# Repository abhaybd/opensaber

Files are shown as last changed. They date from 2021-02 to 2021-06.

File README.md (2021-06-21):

# OpenSaber

An LED lightsaber, designed and built from scratch. This project took a while to complete, mostly due to classes and tests, but it's finally done!

<p align="center">
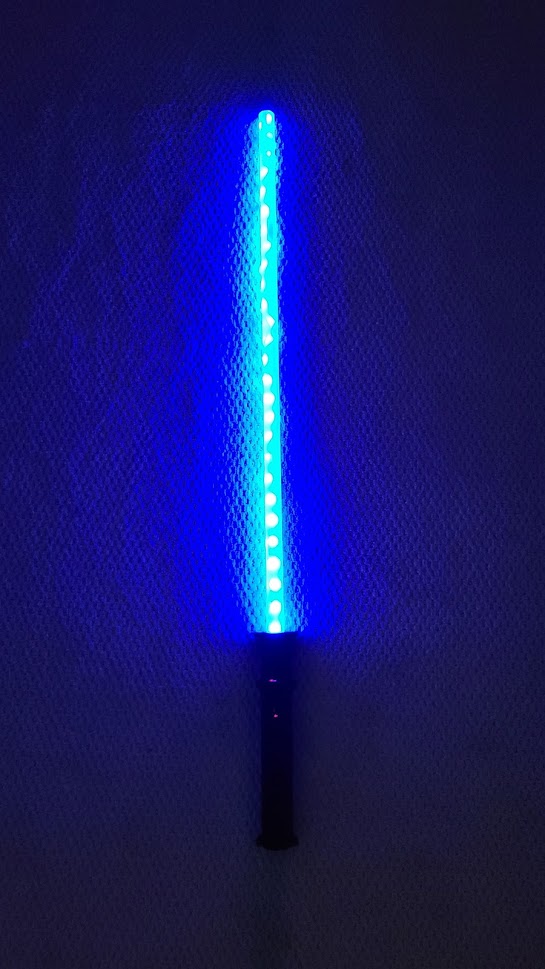
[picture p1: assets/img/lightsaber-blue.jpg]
    
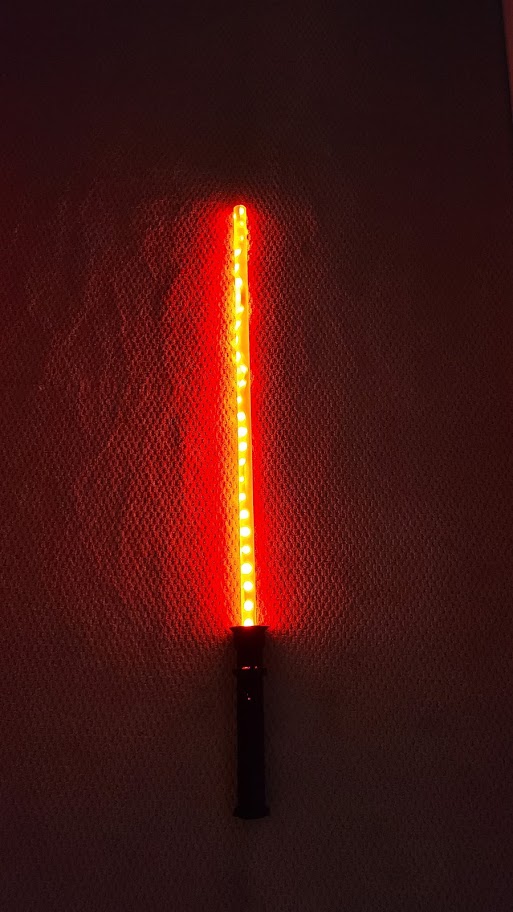
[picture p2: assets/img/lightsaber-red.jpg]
    
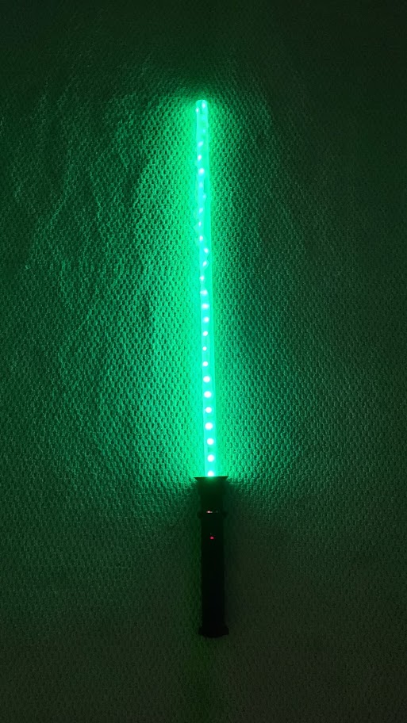
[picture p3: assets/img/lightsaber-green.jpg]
    
</p>

My goal with this document isn't to analyze every step of the process in building this project, but merely to point out the parts that I found particularly interesting, challenging or fun. Therefore, this probably isn't a proper "postmortem", but rather a "highlights reel", maybe.

## High-Level Overview

I designed hilt of the lightsaber using Fusion360, and then 3d-printed it. The hilt is made of 5 pieces, and held together by screws. The blade is a frosted acrylic tube, with a strip of LEDs inside.

### Electronics

Inside the hilt, there is a microcontroller (Trinket M0), a gyroscope (MPU6050), a speaker, an audio amplifier, a power converter (5V boost), and a Li-Ion battery. The single microcontroller runs the lights, sounds, user input, and reads sensor information from the gyro. Using the rotational velocity information, the brightness of the blade and the volume of the lightsaber is dynamically adjusted according to how fast the lightsaber is swinging, which makes the blade feel more "alive". The LED strip in the blade is individually-addressable, allowing the  blade to be any color, as well as having ignition and extinguishing animations.

### Physical

Since my 3D printer has a size limitation of <6 inches in each dimension, the hilt needed to be printed in several pieces. There are 2 back pieces, 2 front pieces, and then an emitter piece, which is where the blade is mounted. The electronics are mounted into the back pieces, and the user controls are mounted on the front pieces.

I'm not particularly skilled with CAD, so the first draft of the hilt was pretty bad. I highly overestimated the space I had inside the hilt, so I designed hilt to be mostly solid plastic, with mounting points for the electronics. 

<p align="center">
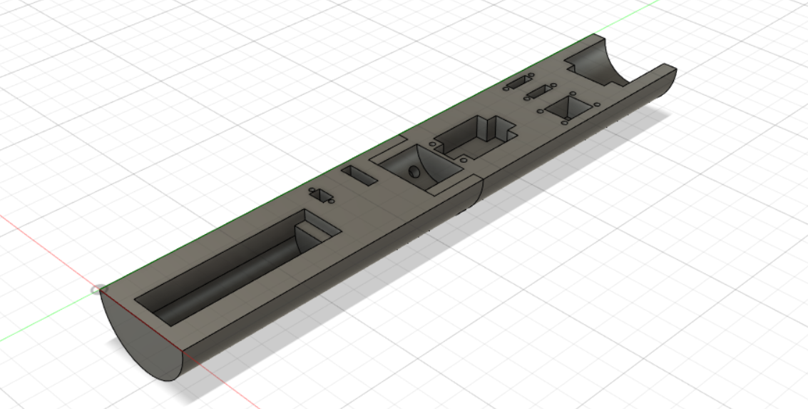
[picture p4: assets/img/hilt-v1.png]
Hilt-V1
    
</p>

As you can see, in the second iteration I tried to mount electronics on the inner walls, resulting in much more space.

<p align="center">
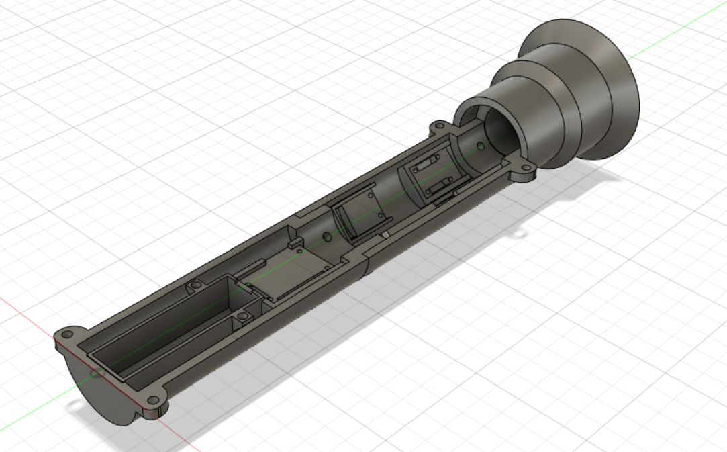
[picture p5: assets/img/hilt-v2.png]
Hilt-v2
    
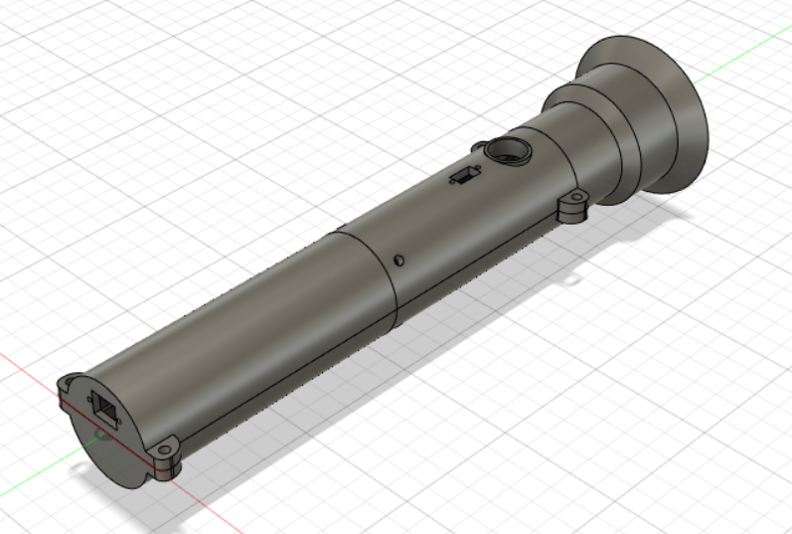
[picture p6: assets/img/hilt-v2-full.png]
    
</p>

You'll notice that on the bottom of the hilt there's a hole. This was intended for a charging cable, so the lightsaber could be charged by just plugging it in. However, with the amount of wires filling up the inside of the hilt, there was no room for such a thick cable, so that had to be scrapped. As a result, unfortunately, in order to charge the battery, the hilt must be disassembled.

## Roadblock - LED Write Latency

A major problem I ran into early in the project was the issue of having the singular microcontroller driving everything at the same time. For example, while the lightsaber is on, the microcontroller must monitor the gyro, send audio signals, adjust the LEDs, and handle user input. 

The microcontroller sends audio signals using an analog output, which allows it to dynamically change the volume according to the speed of the saber. A downside of this, however, is that audio data cannot be buffered, which would allow for much more flexible timing. Therefore, the audio must be played real-time, which means that the timing should be very consistent. While the lightsaber is on, the sound is played back at a frequency of 6kHz, which means that the loop period should be, at maximum, 0.000167 seconds, or 167 microseconds. Normally, this should be fine, and would be well within the abilities of the microcontroller. However, updating the LED strip complicates things, for a few reasons.

First, updating the LEDs is fairly expensive, and would cause the loop time to exceed the maximum allowable period. Second, the library being used for the LEDs, the Adafruit NeoPixel library, suspends interrupts while running. Since all mechanisms to measure time depend on interrupts, the system would have no way of knowing how much time was spent commanding the LEDs, and would therefore mess up all scheduling logic.

The best solution I found through research was to change the LED update mechanism to DMA. DMA, or Direct Memory Access, would essentially repurpose the communication hardware on the microcontroller (such as I2C, SPI, etc.) to instead send signals to the LEDs. Since this communication is handled by the hardware, this would happen completely independently of the CPU, so updating the LEDs would become absolutely free, in terms of CPU time.

However, an issue was that the communication hardware was already in use, since the gyro uses I2C (a communication protocol) to send data to the microcontroller. The microcontroller can't do both DMA and I2C at the same time, which is obviously a problem.

My solution to this problem was to bit-bang the I2C communication with the gyro. "Bit-banging" is when you use software to do things that would normally be done by hardware. That is, the protocol would be handled by individually flipping pins low and high in software. Since the existing gyro library uses the hardware I2C, I had to rewrite the gyro library from scratch to use the bit-banged I2C implementation. There were a lot of little bugs that came up here, since I was trying to get meaningful information by writing low-level communication from scratch. After a while (and frying a gyro) I was able to iron out all the issues with my gyro library, and it's working pretty reliably.

Obviously, since the I2C is now being run in software, we lose some of the advantage we gained from switching the LEDs to DMA. However, it's still a significant net-positive, since the bit-banged I2C is still reasonably fast.

The new code can comfortably run everything at the required 6kHz update speed, so everything works like a charm. In fact, during the ignition and extinguish animations, since there is no gyro needed, the cycle is run at 12kHz instead of 6, resulting in a little better sound quality.

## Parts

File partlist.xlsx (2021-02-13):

Name | Type | Notes | Link | Qty | Price | Total for Part | Dims (mm)
Trinket M0 | Microcontroller |  | https://www.adafruit.com/product/3500 | 1 | $8.95 | $8.95 | 27 x 15.3 x 2.75 | Subtotal: | $86.45
NeoPixel LED Strip | LED Strip | 1m each, 30LED/m | https://www.adafruit.com/product/4801 | 2 | $12.50 | $25.00 |  | Est. Total: | $106.10
Li-Ion Battery | Battery pack | 3.7V @ 2.2Ah | https://www.adafruit.com/product/1781 | 1 | $9.95 | $9.95 | 69 x 18 x 18
PowerBoost 500 | Boost Converter | Also charges battery | https://www.adafruit.com/product/1944 | 1 | $14.95 | $14.95 | 22 x 37 x 2
6-DoF Accel+Gyro | Accel+Gyro | I2C | https://www.adafruit.com/product/3886 | 1 | $6.95 | $6.95 | 26 x 17.8 x 4.6
FtM Micro USB | Cable | For power to boost | https://www.adafruit.com/product/3258 | 1 | $4.95 | $4.95
Wire spool - 25ft | Wires | Solid core, 22awg | https://www.adafruit.com/product/288 | 1 | $2.95 | $2.95
3-wire block | Wire connector | pack of 3 | https://www.adafruit.com/product/866 | 1 | $4.95 | $4.95 | 8.3 x 18.6 x 29.9
Pushbutton | Button | Normal open | https://www.adafruit.com/product/1505 | 1 | $0.95 | $0.95 | 15 x 15.5
JST socket to cable | Wires | 200mm | https://www.adafruit.com/product/4046 | 1 | $0.95 | $0.95
Audio Amp | Audio | 2.5W | https://www.adafruit.com/product/2130 | 1 | $3.95 | $3.95
Mini speaker | Speaker | 8ohm 1W | https://www.adafruit.com/product/3923 | 1 | $1.95 | $1.95

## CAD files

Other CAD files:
assets/cad/Hilt.f3d

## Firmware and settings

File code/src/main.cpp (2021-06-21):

#include <Arduino.h>
#include <Adafruit_NeoPixel_ZeroDMA.h>

#include <cmath>

#include "MPU6050_Gyro.h"

#undef roundf

// import animation sounds
#include "IgnitionSound.h"
#include "HumSound.h"
#include "Extinguish.h"

//#define DEBUG
//#define GYRO_OPTIONAL

// dma requires pin 4
constexpr int LED_PIN = 4;

// 60 LEDS, where the middle of the strip is the tip of the blade, and the ends of the strip is the base
constexpr int NUM_LEDS = 59;
constexpr int LED_IDX_START = 0;
constexpr int LED_IDX_MIDDLE = 29;
constexpr int LED_IDX_END = 58;

constexpr int AUDIO_PIN = A0;

constexpr int BUTTON_PIN = 3;

constexpr int DAC_PRECISION = 10;

constexpr uint64_t US_PER_SEC = 1000000ull;

MPU6050_Gyro gyro(false, 0, 2);
Adafruit_NeoPixel_ZeroDMA leds(NUM_LEDS, LED_PIN, NEO_GRB + NEO_KHZ800);

constexpr uint8_t baselineBrightness = 128; // unitless, out of 255
constexpr uint8_t maxBrightness = 255; // unitless, out of 255
constexpr ulong gyroUpdatePeriod = 50000; // microseconds
constexpr float maxRotVel = 200; // degrees per second
float humMaxScaleFactor; // initialized in setup()
constexpr uint CHANGE_COLOR_PRESS_DURATION = 1000; // ms
constexpr uint EXTINGUISH_PRESS_DURATION = 50; // ms
const int colors[] = {0xFF0000, 0x00FF00, 0x0000FF, 0xFFFF00};

// state variables
uint8_t colorIndex = 0;
int color = colors[colorIndex];
bool gyroInitialized = false;
bool shouldExtinguish = false;
ulong buttonPressedTime = millis();

template<typename T>
float maxScaleFactor(uint size, const T sound[], float maxVal) {
    if (size == 0) return 1;
    T max = sound[0];
    for (uint i = 1; i < size; i++) {
        if (max < sound[i]) max = sound[i];
    }
    return max == 0 ? 1 : maxVal / static_cast<float>(max);
}

template<typename T>
T clamp(T val, T low, T high) {
    return val < low ? low : (val > high ? high : val);
}

template<typename T, int size>
constexpr uint arrLen(T(&)[size]) {
    return size;
}

void writeAudio(uint value, int precision) {
    // shift either left or right as necessary
    if (precision > DAC_PRECISION) {
        value >>= precision - DAC_PRECISION;
    } else if (precision < DAC_PRECISION) {
        value <<= DAC_PRECISION - precision;
    }
    // this method internally masks the 10 LSB, so we don't have to
    analogWrite(AUDIO_PIN, value);
}

[[noreturn]] void end(bool flashError = true) {
    leds.clear();
    writeAudio(0, DAC_PRECISION);
    while (true) {
        if (flashError) {
            int errorColor = 0x800000;
            leds.fill(errorColor);
            leds.show();
            delay(1000);

            leds.clear();
            leds.show();
            delay(1000);
        }
    }
}

float getRotVel() {
    RotVel rotVel{};
    gyro.get(rotVel);
    // magnitude of axis-angle representation
    return hypotf(rotVel.x, rotVel.z); // we don't care about y rotation, since that's just roll
}

// extinguish and turn off the blade
void extinguish() {
    // disable interrupt while extinguishing
    detachInterrupt(digitalPinToInterrupt(BUTTON_PIN));

    // extinguish leds from top to bottom
    constexpr uint64_t soundLen = arrLen(extinguishSound.sound);
    uint soundTimeMicros = soundLen * US_PER_SEC / extinguishSound.freq;
    int soundIdx = -1; // the last sound sample that has been played
    // these represent the largest and smallest indexes that have not yet been turned off
    int oldLed1Idx = LED_IDX_MIDDLE; // counts down
    int oldLed2Idx = LED_IDX_MIDDLE; // counts down
    ulong time = micros();
    ulong start = time;
    constexpr int OFF_COLOR = 0;
    constexpr uint extinguishTime = extinguishEnd - extinguishStart;

    while (time - start < soundTimeMicros) {
        uint elapsedTime = time - start;
        // the intermediate cast to ull is to prevent overflow from multiplication
        int newSoundIdx = static_cast<int>(static_cast<uint64_t>(elapsedTime) * extinguishSound.freq / US_PER_SEC);
        if (newSoundIdx > soundIdx) {
            soundIdx = newSoundIdx;
            writeAudio(extinguishSound.sound[soundIdx], extinguishSound.precision);

            if (elapsedTime >= extinguishStart) {
                // write to leds
                uint elapsedTimeLed = clamp(elapsedTime - extinguishStart, 0u, extinguishTime);
                // interpolate the elapsed time between the middle and both the start and end
                int led1Idx = static_cast<int>(
                        LED_IDX_MIDDLE - ((elapsedTimeLed * (LED_IDX_MIDDLE - LED_IDX_START)) / extinguishTime));
                int led2Idx = static_cast<int>(
                        LED_IDX_MIDDLE + ((elapsedTimeLed * (LED_IDX_END - LED_IDX_MIDDLE)) / extinguishTime));

                bool shouldShow = false;
                // led 1 counts down from MIDDLE
                while (oldLed1Idx >= led1Idx) {
                    leds.setPixelColor(oldLed1Idx--, OFF_COLOR);
                    shouldShow = true;
                }
                // led 2 counts up from MIDDLE
                while (oldLed2Idx <= led2Idx) {
                    leds.setPixelColor(oldLed2Idx++, OFF_COLOR);
                    shouldShow = true;
                }
                if (shouldShow) {
                    leds.show();
                }
            }
        }
        time = micros();
    }

    leds.clear();
    leds.show();
}

void buttonInterrupt() {
    // pressed = low, released = high
    if (digitalRead(BUTTON_PIN) == LOW) {
        buttonPressedTime = millis();
    } else {
        ulong elapsed = millis() - buttonPressedTime;
        if (elapsed >= CHANGE_COLOR_PRESS_DURATION) {
            colorIndex = (colorIndex + 1) % arrLen(colors);
        } else if (elapsed >= EXTINGUISH_PRESS_DURATION) {
            shouldExtinguish = true;
        }
    }
}

void ignite() {
    // ignite leds from bottom to top
    constexpr uint64_t soundLen = arrLen(ignitionSound.sound);
    uint soundTimeMicros = soundLen * US_PER_SEC / ignitionSound.freq;
    int soundIdx = -1; // the last sound sample that has been played
    // these represent the smallest index that has not been lit up
    uint oldLed1Idx = 0; // counts up
    uint oldLed2Idx = LED_IDX_END; // counts down
    ulong time = micros();
    ulong start = time;

    int numPlayed = 0;

    while (time - start < soundTimeMicros) {
        uint elapsedTime = time - start;
        // the intermediate cast to ull is to prevent overflow from multiplication
        int newSoundIdx = static_cast<int>(static_cast<uint64_t>(elapsedTime) * ignitionSound.freq / US_PER_SEC);
        if (newSoundIdx > soundIdx) {
            soundIdx = newSoundIdx;
            numPlayed++;
            writeAudio(ignitionSound.sound[soundIdx], ignitionSound.precision);

            // write to leds
            uint elapsedTimeLed = clamp(elapsedTime, 0u, igniteTime);
            uint led1Idx = LED_IDX_START + ((elapsedTimeLed * (LED_IDX_MIDDLE - LED_IDX_START)) / igniteTime);
            uint led2Idx = LED_IDX_END - ((elapsedTimeLed * (LED_IDX_END - LED_IDX_MIDDLE)) / igniteTime);

            bool shouldShow = false;
            // led 1 counts up from START
            while (oldLed1Idx <= led1Idx) {
                leds.setPixelColor(oldLed1Idx++, color);
                shouldShow = true;
            }
            // led 2 counts down from END
            while (oldLed2Idx >= led2Idx) {
                leds.setPixelColor(oldLed2Idx--, color);
                shouldShow = true;
            }
            if (shouldShow) {
                leds.show();
            }
        }
        time = micros();
    }

    // verify that all audio samples were played
    Serial.print("Played ");
    Serial.print(numPlayed);
    Serial.print(" audio samples out of ");
    Serial.println(static_cast<int>(soundLen));

    leds.fill(color, LED_IDX_START, LED_IDX_END - LED_IDX_START + 1);
    leds.show();
}

// Scales a given (biased) audio data point relative to the rotVel.
uint transformHumAudio(float rotVel, uint sample, uint precision) {
    // convert to unbiased, perform scaling, convert back to biased
    auto biasF = static_cast<float>(1 << (precision - 1));
    auto unbiased = static_cast<float>(sample) - biasF;
    float scaleFactor = 1.0f + (humMaxScaleFactor - 1.0f) * rotVel / maxRotVel;
    float scaled = roundf(unbiased * scaleFactor);
    scaled = clamp(scaled, -biasF, biasF - 1);
    return static_cast<uint>(scaled + biasF);
}

void lightsaberLoop() {
    static ulong start = micros();
    static float rotVel = 0;
    ulong time = micros();

    static ulong lastGyroUpdate = micros();
    if (gyroInitialized && time - lastGyroUpdate >= gyroUpdatePeriod) {
        lastGyroUpdate = time;
        rotVel = clamp(getRotVel(), 0.0f, maxRotVel);

        float additionalBrightness = (rotVel / maxRotVel) * (maxBrightness - baselineBrightness);
        uint8_t brightness = baselineBrightness + static_cast<uint8_t>(roundf(additionalBrightness));
        leds.setBrightness(Adafruit_NeoPixel_ZeroDMA::gamma8(brightness));
        leds.show();
    }

    static int oldSoundIdx = -1;
    constexpr uint64_t audioLenMicros = arrLen(humSound.sound) * US_PER_SEC / humSound.freq;
    ulong audioTime = (time - start) % audioLenMicros;
    int soundIdx = static_cast<int>(static_cast<uint64_t>(audioTime) * humSound.freq / US_PER_SEC);
    if (soundIdx != oldSoundIdx) {
        uint val = transformHumAudio(rotVel, humSound.sound[soundIdx], humSound.precision);
        writeAudio(val, humSound.precision);
        oldSoundIdx = soundIdx;
    }
}

void setup() {
#ifdef DEBUG
    while (!Serial); // for debugging
#endif
    leds.begin();
    leds.setBrightness(Adafruit_NeoPixel_ZeroDMA::gamma8(baselineBrightness));
    leds.clear();
    leds.show();
    gyroInitialized = true;
    if (!gyro.begin()) {
        gyroInitialized = false;
        Serial.println("Failed to find gyro!");
#ifndef GYRO_OPTIONAL
        end();
#endif
    }
    humMaxScaleFactor = maxScaleFactor(arrLen(humSound.sound), humSound.sound,
                                       static_cast<float>((1 << humSound.precision) - 1));
    ignite(); // synchronously run the ignition routine

    pinMode(BUTTON_PIN, INPUT_PULLUP);
    attachInterrupt(digitalPinToInterrupt(BUTTON_PIN), buttonInterrupt, CHANGE);
}

void loop() {
    // if necessary, extinguish and then end
    if (shouldExtinguish) {
        extinguish();
        end(false);
    }
    if (colors[colorIndex] != color) {
        color = colors[colorIndex];
        leds.fill(color);
        leds.show();
    }
    lightsaberLoop();
}

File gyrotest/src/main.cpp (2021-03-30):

#include <Arduino.h>
#include <MPU6050_Gyro.h>
#include <Adafruit_MPU6050.h>
#include <Adafruit_DotStar.h>

Adafruit_DotStar led(1, 7, 8, DOTSTAR_BGR);


[[noreturn]] void testSWI2C() {
    MPU6050_Gyro gyro(false, 0, 2);

    Serial.println("Testing SW I2C with gyro...");
    bool b = gyro.begin();
    if (!b) {
        Serial.println("Failed to boot up!");
        led.fill(0xFF0000);
        led.show();
        while (true);
    } else {
        led.fill(0x0000FF);
        led.show();
//        gyro.setGyroFilterBandwidth(FilterBandwidth::HZ_98);
        gyro.setBias({-3.323f,-0.212f, 1.461});
        RotVel vel{};
        while (true) {
            ulong start = micros();
            gyro.get(vel);
            ulong elapsed = micros() - start;
            Serial.print("X: ");
            Serial.print(vel.x);
            Serial.print(", Y: ");
            Serial.print(vel.y);
            Serial.print(", Z: ");
            Serial.print(vel.z);
            Serial.println();
            Serial.print("Elapsed: ");
            Serial.print(elapsed);
            Serial.println("us");
            delay(500);
        }
    }
}

[[noreturn]] void testHWI2C() {
    Adafruit_MPU6050 mpu;
    Adafruit_MPU6050_Gyro gyro(&mpu);

    Serial.println("Testing HW I2C with gyro...");
    if (!mpu.begin()) {
        Serial.println("Failed to connect!");
        led.fill(0xFF0000);
        led.show();
        while (true);
    } else {
        sensors_event_t event;
        led.fill(0x0000FF);
        led.show();
        while (true) {
            delay(500);
            gyro.getEvent(&event);
            Serial.print("GYRO: X=");
            constexpr float degPerRad = 180.0f / M_PI;
            Serial.print(event.gyro.x * degPerRad);
            Serial.print(", Y=");
            Serial.print(event.gyro.y * degPerRad);
            Serial.print(", Z=");
            Serial.println(event.gyro.z * degPerRad);
        }
    }
}

void setup() {
// write your initialization code here
    Serial.begin(9600);
    led.begin();
    led.fill();
    led.show();

//    pinMode(0, OUTPUT);
//    pinMode(2, OUTPUT);
//    digitalWrite(0, HIGH);
//    digitalWrite(2, HIGH);
    while (!Serial);

    delay(1000);

//    testHWI2C();
    testSWI2C();
}

void loop() {
//    Serial.println("Hello!");
//    delay(500);
}

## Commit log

2021-02-09 Added partslist
    [partlist.xlsx]
2021-02-10 Updated partslist
    [partlist.xlsx]
2021-02-13 More partslist updates
    [partlist.xlsx]
2021-02-19 Added some code to bitbang i2c
2021-02-19 Added gyro class
2021-02-20 Filled out gyro implementation, renamed files
2021-02-23 Added code for testing gyro
2021-02-23 Fixed bug in getting gyro data, wake up sensor
    [main.cpp]
2021-02-27 Switched to bitbanged gyro library
2021-02-27 Switched to dma for leds
2021-02-27 Bug fixes and improvements
    [main.cpp]
2021-02-27 Disable print statement
2021-02-27 Print number of audio samples played
2021-02-28 Replace macros with typesafe equivalents
    [main.cpp]
2021-03-06 Fixed audio pin
2021-03-21 Added flag to make gyro optional
2021-03-22 Added led signal to gyrotest, minor debugging code
2021-03-30 Updates to gyro test
2021-03-30 Added some assets
    [Hilt.f3d]
2021-04-01 Added rebiasing code for audio, remixed ignition for better flow
2021-04-01 corrected gyro axes
2021-05-21 Adjusted thresholds, added gamma correction
    [main.cpp]
2021-05-21 Added interrupt for button
2021-05-22 Fixed some bugs, adjusted constants
    [main.cpp]
2021-06-02 Dont extinguish in interrupt thread
2021-06-15 Fix bugs, improve hum sound
    [main.cpp]
2021-06-20 Improved ignition sound, fixed brightness bug
    [main.cpp]
2021-06-21 Removed temporary code, uncommented interrupt
2021-06-21 Improved CAD screenshots
